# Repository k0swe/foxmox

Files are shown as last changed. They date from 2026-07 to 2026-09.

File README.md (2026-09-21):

# FoxMox V2.6

A KiCad reproduction of Larry Benko **W0QE**'s _Low Power FoxMOX Controller
V2.6_ (December 2004), transcribed by Chris Keller **K0SWE**.

FoxMox is a PIC16F84A-based amateur-radio foxhunt/ARDF beacon controller. It
keys and modulates an Alinco DJ-S11 through the radio's 2.5 mm microphone jack,
is powered by the jack's microphone-bias supply, and uses two hexadecimal rotary
switches for field configuration.

This repository includes the reconstructed hardware, the original scanned
schematic, recovered and hardware-tested firmware, readable assembly source, and
field operating instructions.

## Repository contents

| Path | Purpose |
| --- | --- |
| [`USER-GUIDE.md`](USER-GUIDE.md) | Field switch settings, timing profiles, and staggered five-fox startup. |
| [`Hardware/README.md`](Hardware/README.md) | Circuit behavior, radio interface, power constraints, R5 service strap, and bench checks. |
| [`Hardware/W0QE FoxMox scanned.pdf`](<Hardware/W0QE FoxMox scanned.pdf>) | Scan of the original W0QE schematic and source of truth for the hardware transcription. |
| `Hardware/foxmox.kicad_sch` / `Hardware/foxmox.kicad_pcb` | Reconstructed KiCad schematic and PCB. |
| [`Hardware/foxmox.pdf`](Hardware/foxmox.pdf) | Exported reconstructed schematic. |
| [`Firmware/README.md`](Firmware/README.md) | PIC programming, clock calibration, assembly builds, regression verification, and callsign generation. |
| `Firmware/foxmox-v2.6.hex` | Original recovered, hardware-tested PIC programming image. |
| `Firmware/foxmox-v2.6.asm` | Validated, readable gpasm source that reproduces the recovered image exactly. |

## Quick start

- For field setup, begin with [`USER-GUIDE.md`](USER-GUIDE.md).
- For hardware construction or troubleshooting, see
  [`Hardware/README.md`](Hardware/README.md).
- For PIC programming or firmware builds, see
  [`Firmware/README.md`](Firmware/README.md).

The default assembly build identifies as **N0PUF** and is regression-tested
byte-for-byte against the recovered programming image.

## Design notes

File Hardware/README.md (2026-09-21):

# FoxMox hardware

This directory contains the complete hardware design and its source references
for Larry Benko **W0QE**'s _Low Power FoxMOX Controller V2.6_ (December 2004),
transcribed by Chris Keller **K0SWE**.

| Path | Purpose |
| --- | --- |
| `foxmox.kicad_pro` | KiCad project entry point. |
| `foxmox.kicad_sch` | Reconstructed schematic. |
| `foxmox.kicad_pcb` | PCB layout. |
| `foxmox.pdf` | PDF export of the reconstructed schematic. |
| `W0QE FoxMox scanned.pdf` | Scan of Larry Benko W0QE's original schematic; source of truth for transcription. |
| `fp-lib-table`, `sym-lib-table` | Project-local KiCad library tables. |
| `Libraries/` | Project-local symbols, footprints, and 3D models. |
| `Datasheets/` | Component datasheets. |

Open `foxmox.kicad_pro` from this directory. Library references use
`${KIPRJMOD}/Libraries/...`, so moving the project and `Libraries/` together
preserves their relative paths.

The target radio in this build is the **Alinco DJ-S11**, connected through its
2.5 mm microphone jack.

## How the controller keys the radio

The DJ-S11 microphone jack has ground, a bias rail, and audio, but no separate
PTT contact. The microphone tip serves as both the audio input and PTT sense.
The radio biases that contact to power an electret microphone and watches its DC
level: pulling it toward ground through a resistor keys the transmitter;
releasing it returns the radio to receive. Transmit audio is AC-coupled onto the
same contact.

This resistive keying arrangement is common on Alinco, Icom, and Yaesu handheld
microphone interfaces. It does not depend on a VOX setting in the radio; VOX
accessories for these radios implement their own resistive pull-down. Kenwood
accessory wiring is a notable exception because it commonly provides a separate
PTT contact.

### Audio path — PIC RA0, pin 17

```text
RA0 ── R1 20k ── R2 5k pot ──(wiper)── C4 1 µF ── P1 tip
                      └── bottom ── GND
```

RA0 generates the square-wave tone. R1 and R2 attenuate it, while C4 blocks DC
so the tone does not disturb the keying level.

W0QE annotated the original drawing:

> Adjust for 20 to 40 mV peak to peak. Or set R2 for ~300 ohms from wiper to
> ground.

That setting is internally consistent: `3.0 V × 300 / 25000 ≈ 36 mV`. Avoid
excessive drive; the source waveform is already square and harmonic-rich.

### PTT path — PIC RA1, pin 18

```text
RA1 ── R3 20k ── Q1 base (2N2222A, emitter → GND)
                 Q1 collector ── R4 2.7k ── P1 tip
```

RA1 high saturates Q1 and pulls the microphone tip toward ground through R4.
**R4, 2.7 kΩ, is the radio's keying resistor.** RA1 low turns Q1 off and allows
the microphone contact to return to its bias voltage.

Both paths meet at the microphone tip. In the PCB netlist, `Net-(C4-Pad2)`
contains `C4.2`, `P1.T`, and `R4.2`.

## Power source and current budget

The controller has no battery of its own. It is parasitically powered by the
radio's microphone-bias rail:

```text
P1 ring ── S3 (SPDT power switch) ── VDD ── U1.14, U1.4 (MCLR), C3, D1, TP1
P1 sleeve ── GND
```

W0QE recorded:

> Measured current draw @ 3.0 V from Ring to Sleeve = **0.5 mA idle, 0.9 mA
> transmitting**

This sub-milliamp supply is a binding design constraint. It explains the
PIC16F84, resistively attenuated square-wave audio, and absence of more
power-hungry circuitry. Before substituting another MCU, verify that its
complete idle and transmit current does not collapse the microphone-bias rail or
false-key the radio.

D1 is a 6.2 V zener used for overvoltage protection. It is not regulating the
normal approximately 3 V supply.

## R5 is the boot/service-mode strap

R5, 10 kΩ, is intentionally connected between **RA2 (PIC pin 1)** and **RA3 (PIC
pin 2)**. **RA4/T0CKI (PIC pin 3) is unconnected. Do not move R5 to RA4.**

The original scan is easy to misread:

1. The `R5 10k` text is printed below its resistor body, placing the label near
   the RA4 row even though the component itself connects RA2 to RA3. Component
   label placement in this drawing is not a reliable indication of connectivity.
2. The X on the RA4 row is a printed no-connect mark. The pin stub ends at that
   mark; it is not a wire crossed out by hand. Pixel measurements support that
   reading: its darkness matches printed material rather than the lighter pencil
   handwriting elsewhere on the scan.

   | Scan feature                     | Mean gray |
   | -------------------------------- | --------: |
   | Printed wire                     |        73 |
   | RA4 X mark                       |        81 |
   | Printed text                     |        89 |
   | Pencil handwriting at top margin |       140 |

The reconstructed schematic has an explicit RA4 no-connect at `(97.79, 105.41)`;
with U1 placed at `(80.01, 110.49)`, that location resolves to PIC pin 3. The
PCB independently names the pad `unconnected-(U1-TOCKI{slash}RA4-Pad3)`. The
reconstructed schematic and PCB therefore agree.

The firmware also proves R5's purpose: at reset RA3 is driven high while RA2 is
an input, so R5 pulls RA2 high for normal startup. Holding RA2 low during
startup enters the clock-calibration service mode; the firmware waits for RA2 to
be released before continuing. Moving R5 to RA4 would break that boot test.

The service-mode procedure is documented in
[`../Firmware/README.md`](../Firmware/README.md).

## Bench checks with an Alinco DJ-S11

Before relying on a rebuilt controller in the field, check it with the actual
radio and cable:

1. **Bias supply:** measure approximately 3 V from ring to sleeve and confirm it
   can source at least 1 mA without excessive sag.
2. **PTT keying:** confirm that the 2.7 kΩ pull-down keys reliably with both a
   fresh radio battery and a nearly discharged one. The microphone-bias voltage
   can move with battery condition.
3. **Audio level:** begin with R2 adjusted to approximately 300 Ω from wiper to
   ground, then verify 20–40 mV peak-to-peak or check deviation on a service
   monitor or trusted receiver.

## Verifying the transcription

The scanned schematic is lossy and its geometry is easy to misread. Use these
sources in descending order of confidence:

1. Treat `W0QE FoxMox scanned.pdf` as the source of truth for the original
   design.
2. Use the resolved nets in `foxmox.kicad_pcb` when checking the reconstructed
   connectivity. Footprint pad records carry their net names and avoid visual
   wire-tracing mistakes.
3. Cross-check hardware-dependent behavior against
   [`../Firmware/foxmox-v2.6.asm`](../Firmware/foxmox-v2.6.asm).
4. For close inspection of the scan, render it at high resolution:

   ```sh
   pdftoppm -r 300 -png "Hardware/W0QE FoxMox scanned.pdf" out
   ```

`Hardware/.history/` and `*.kicad_prl` are intentionally ignored by the outer
repository. They are local KiCad state, not versioned design artifacts.

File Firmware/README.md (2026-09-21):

# FoxMox firmware

This directory contains the recovered and hardware-tested firmware for the W0QE
FoxMOX V2.6 controller built around a PIC16F84A.

## Contents

| Path | Purpose |
| --- | --- |
| `foxmox-v2.6.asm` | Validated, readable gpasm source for the complete firmware. |
| `foxmox-v2.6.hex` | Original recovered programming image and exact-build regression oracle. |
| `Makefile` | Default exact build plus custom-callsign image builds. |
| `emit_callsign.py` | Validates a callsign and emits its Morse calls plus layout padding. |
| `verify_image.py` | Compares all programmed regions against the recovered image. |
| `canonicalize_hex.py` | Normalizes gpasm output to the recovered Intel HEX representation. |
| `test_emit_callsign.py` | Unit tests for callsign generation and fixed-layout compensation. |
| `requirements.txt` | Pinned Python package needed to operate a K150 with `picpro`. |

`foxmox-v2.6.hex` was reconstructed from two original FoxMox PIC16F84A chips.
Each chip was read twice. All four ROM reads and all four configuration reads
matched. The two reads from each chip's EEPROM matched; the committed image uses
the first chip's EEPROM. A newly programmed blank PIC reproduced the correct
behavior in an original FoxMox circuit.

SHA-256:

```text
fd2546d702d7f152492bd81f077fed141b5110a9ec950f8becbee85d6fce2018  foxmox-v2.6.hex
```

The disposable raw binary reads were removed after reconstruction and
verification. Their SHA-256 provenance is retained here:

| Original reads | SHA-256 |
| --- | --- |
| ROM reads 1–4 | `546781166e6c349ccbb167d5767dacbf99e84a844c02573d8a7d724120fe6fbd` |
| Config reads 1–4 | `ef243db2cd17e4bd231702d4772631d3d2b1c6517537b5ffe5ee716e1d2c0511` |
| EEPROM reads 1–2 (chip 1; used here) | `1717c8d193e79f42a47fa1c73697095e1c3cf7151fb5c31dcc71067034cc6e31` |
| EEPROM reads 3–4 (chip 2) | `ec9046ee89c522c35967271c6c3d923df622bfac4652ae824c0369186abe2a14` |

The two EEPROM images differed only at logical addresses `0x00` and `0x28`.

## K150 placement for the PIC16F84A

On the common 40-pin K150 ZIF socket:

- orient PIC pin 1 toward the **lever end**;
- align PIC pin 1 with **ZIF position 2**, leaving ZIF position 1 empty;
- the 18-pin device therefore occupies ZIF positions 2–10 and 31–39.

An incorrect position returns plausible-looking default data identical to an
empty socket, including a zero device ID. Correct placement returns the expected
PIC16F84A silicon ID `0x0560`.

Disconnect USB before inserting, removing, or repositioning a PIC.

## Re-create the picpro environment

From the repository root:

```sh
python3 -m venv .venv
.venv/bin/python -m pip install --upgrade pip
.venv/bin/python -m pip install -r Firmware/requirements.txt
```

The tested version is `picpro 0.4.1`. The K150 used here reports firmware
version 3 and the required P18A protocol:

```sh
.venv/bin/picpro programmer_info -p /dev/ttyUSB0
```

Expected:

```text
Firmware version: 3
Protocol version: P18A
```

If access to `/dev/ttyUSB0` is denied, add the user to the distribution's serial
port group (commonly `dialout`) and start a new login session.

## Safely identify and read a chip

Read-only configuration check:

```sh
.venv/bin/picpro read_chip_config -p /dev/ttyUSB0 -t 16f84a
```

A connected PIC16F84A should return `Chip ID: 1376 (0x560)`. The recovered
FoxMox configuration word is `0x3FF1`, decoded as:

```text
WDT = Disabled
PWRTE = Enabled
Oscillator = XT
Code Protect = Disabled
```

Read all three regions as binary files into a scratch directory:

```sh
mkdir -p /tmp/foxmox-read
.venv/bin/picpro dump rom \
  -p /dev/ttyUSB0 -t 16f84a --binary \
  -o /tmp/foxmox-read/rom.bin
.venv/bin/picpro dump eeprom \
  -p /dev/ttyUSB0 -t 16f84a --binary \
  -o /tmp/foxmox-read/eeprom.bin
.venv/bin/picpro dump config \
  -p /dev/ttyUSB0 -t 16f84a --binary \
  -o /tmp/foxmox-read/config.bin
```

Read twice and compare hashes before treating a recovery as trustworthy. The
committed combined HEX remains the canonical recovered image; the disposable
raw-read reconstruction utility was retired after the readable assembly was
proved byte-identical across every programmed region.

## Program and verify a replacement PIC

**Programming erases and overwrites the chip currently in the socket. Never run
this against one of the originals.** Confirm that a replaceable blank PIC is
installed first.

```sh
.venv/bin/picpro program \
  -p /dev/ttyUSB0 -t 16f84a \
  -i Firmware/foxmox-v2.6.hex

.venv/bin/picpro verify \
  -p /dev/ttyUSB0 -t 16f84a \
  -i Firmware/foxmox-v2.6.hex
```

The strongest practical check is to install the replacement in an original
FoxMox controller and confirm its on-air behavior; that validation has already
succeeded for this committed image.

## Calibrate the one-second time base

The firmware stores an unsigned clock-trim byte in data EEPROM address `0x28`.
The recovered chip-1 image contains `0xFF`; this is a runtime setting, not the
PIC programmer's unrelated generic `CAL` field.

Every 64th nominal second, the timer ISR adds the trim byte to that one
software-divider interval. Consequently:

- increasing the value makes firmware seconds and all timed phases **longer**;
- decreasing the value makes them **shorter**;
- one count changes the average rate by approximately **4.472 ppm**.

There is no universal target byte: crystal frequency, loading, supply voltage,
and temperature all affect the correct setting. Measure the assembled controller
rather than copying another unit's value.

The firmware's service interface was reconstructed from code. No surviving
factory instruction identifies the original fixture or contact used to ground
RA2. On an unmodified board, use a temporary, controlled connection to RA2 only
if you are comfortable working directly at the PIC; RA2 is PIC pin 1. During the
boot test RA2 is an input pulled high from RA3 through R5 (10 kOhm). **Do not
leave RA2 grounded:** after service entry the firmware changes RA2 to an output.

### Measure the error

Use a stable reference clock and measure complete PTT cycles rather than Morse
element lengths. A convenient setup is S1=`0` through `4` and S2=`6`, whose
normal cycle is 60 seconds transmitting plus 240 seconds silent, or 300 firmware
seconds. Ignore the one-time transmission immediately after power-on and time
from one later PTT assertion to the same edge after several complete cycles.
Twelve cycles give a nominal one-hour observation.

For a one-hour measurement:

```text
trim change ≈ (3600.000 s - measured seconds) / 0.016091 s
```

Round to the nearest whole count:

- a measurement shorter than 3600 seconds means the firmware is fast, so
  **increase** the trim;
- a measurement longer than 3600 seconds means it is slow, so **decrease** the
  trim.

For an arbitrary observation of `N` nominal firmware seconds, the equivalent
calculation is:

```text
trim change ≈ (N - measured seconds) / (N × 4.47195e-6)
```

This is a first-order correction. Re-measure after adjustment, preferably over a
longer interval and at the expected field temperature.

### Enter service mode and change the value

Service mode keys the transmitter and announces values over the radio. Use a
dummy load or an authorized test frequency and identify as required.

1. Power the controller off.
2. Set **S1=`1` and S2=`2`**. This keeps the combined switch value nonzero while
   selecting a no-change S2 position.
3. Hold RA2 low and apply power.
4. Release RA2. The firmware waits for a stable high level, enters service mode,
   keys the transmitter, and sends the current trim as two hexadecimal Morse
   characters.
5. Use S2 to adjust or hold the value:

   |        S2 position | Service-mode action                                   |
   | -----------------: | :---------------------------------------------------- |
   | `1`, `3`, `5`, `7` | Increment the trim                                    |
   |            `8`–`F` | Decrement the trim                                    |
   |      `2`, `4`, `6` | Hold without changing it                              |
   |                `0` | Exit service mode after the five-second service timer |

   S2 positions that change the value repeat the operation while selected. Each
   new value is written immediately to EEPROM `0x28` and announced in
   hexadecimal Morse. Return S2 to `2` after the desired number of steps.

6. Turn S2 to `0` and wait. The firmware announces the stored value again,
   restarts, and enters normal operation using the new trim.
7. Power off, remove any temporary RA2 connection, restore the desired S1/S2
   operating settings, and repeat the timing measurement.

Do not enter service mode with both switches at zero. That combination branches
to the firmware's halt/blink loop instead of the adjustment interface. The trim
arithmetic wraps at `00`/`FF`; there is no saturation check, so count carefully
near either endpoint.

## Build and verify the assembly source

`foxmox-v2.6.asm` is the maintained firmware source. Every executable program
word is readable gpasm; the remaining `DW 0x3FFF` values intentionally represent
erased reset padding and the variable gap before the fixed page-3 tables.

Install the open-source, MPASM-compatible `gputils` assembler:

```sh
sudo apt install gputils
```

The validated toolchain is `gpasm-1.4.0 #1107 (Jan 1 2021)`. Build the default
`N0PUF` image and compare its program ROM, configuration word, EEPROM, user-ID
nibbles, emitted regions, and canonical Intel HEX against the recovered image:

```sh
make -C Firmware verify
```

The final canonical image is `Firmware/build/foxmox-v2.6.hex`. A successful
build reports both lossless programmed-memory equivalence and byte-for-byte
canonical HEX identity.

### Build a different callsign

The identification callsign is compiled into program memory and defaults to the
recovered value, `N0PUF`. Build a custom alphanumeric callsign with:

```sh
make -C Firmware image CALLSIGN=K0SWE BUILD_DIR=build/K0SWE
```

This creates `Firmware/build/K0SWE/foxmox-v2.6.hex`. Supported characters are
`A-Z` and `0-9`; lowercase is normalized and punctuation is rejected. The
emitter adjusts erased padding so callsigns of different lengths cannot move
`hex_digit_dispatch` from `0x300` or `tone_pattern_lookup` from `0x367`; an
assembler assertion fails closed if the boundary changes.

`make verify` is intentionally limited to `N0PUF`, because a customized image
must differ from the recovered regression oracle. Run the callsign tests alone
with:

```sh
make -C Firmware test
```

Remove generated output with:

```sh
make -C Firmware clean
```

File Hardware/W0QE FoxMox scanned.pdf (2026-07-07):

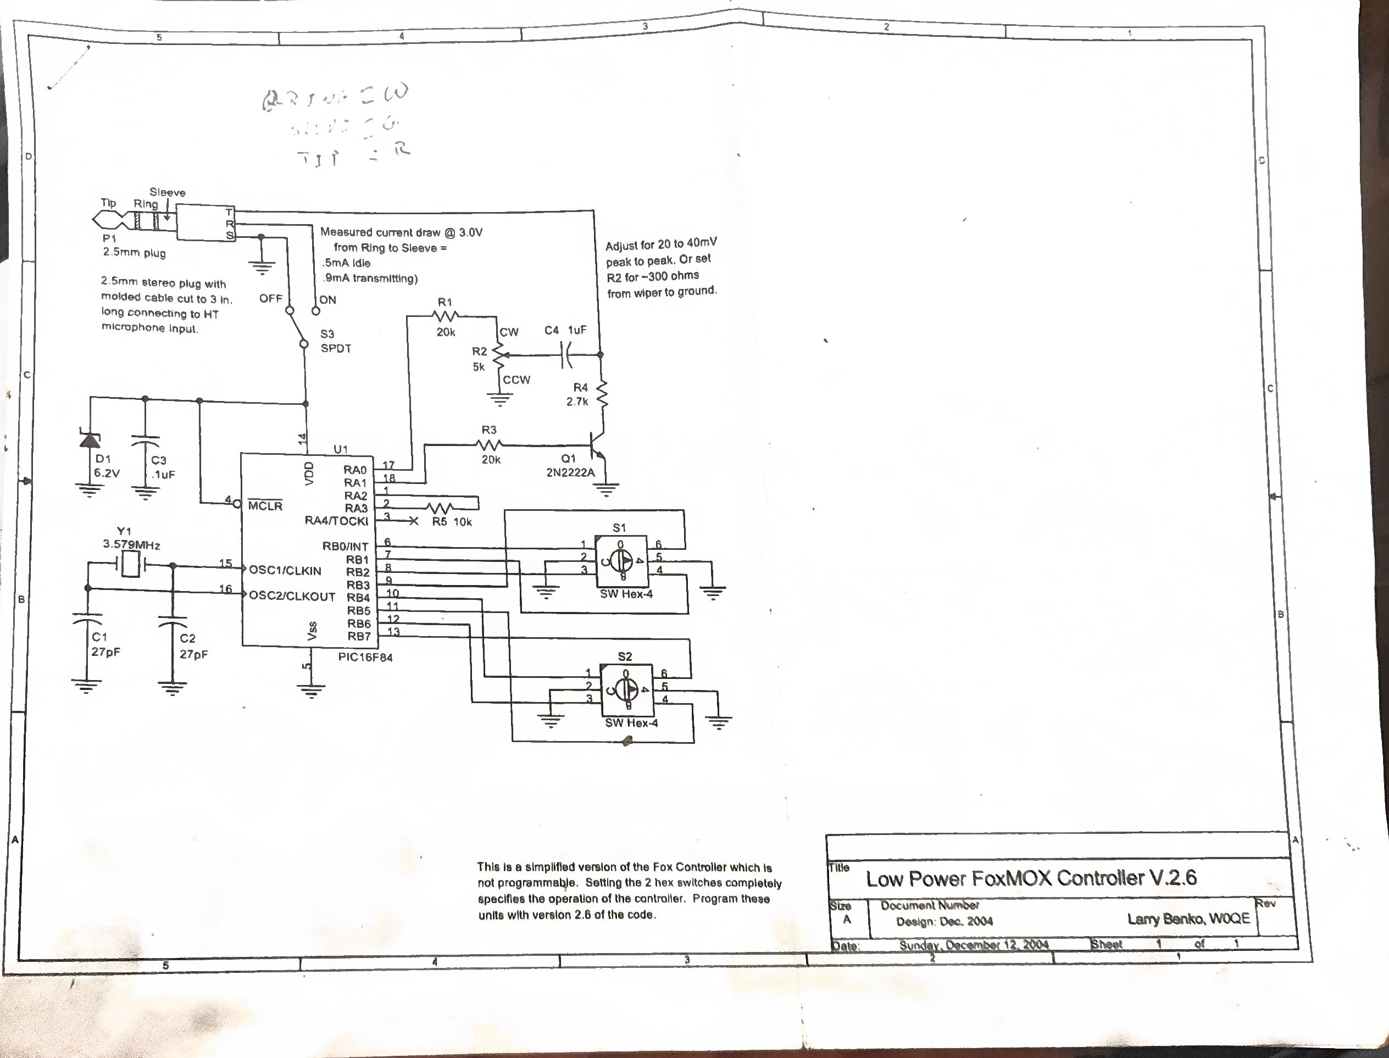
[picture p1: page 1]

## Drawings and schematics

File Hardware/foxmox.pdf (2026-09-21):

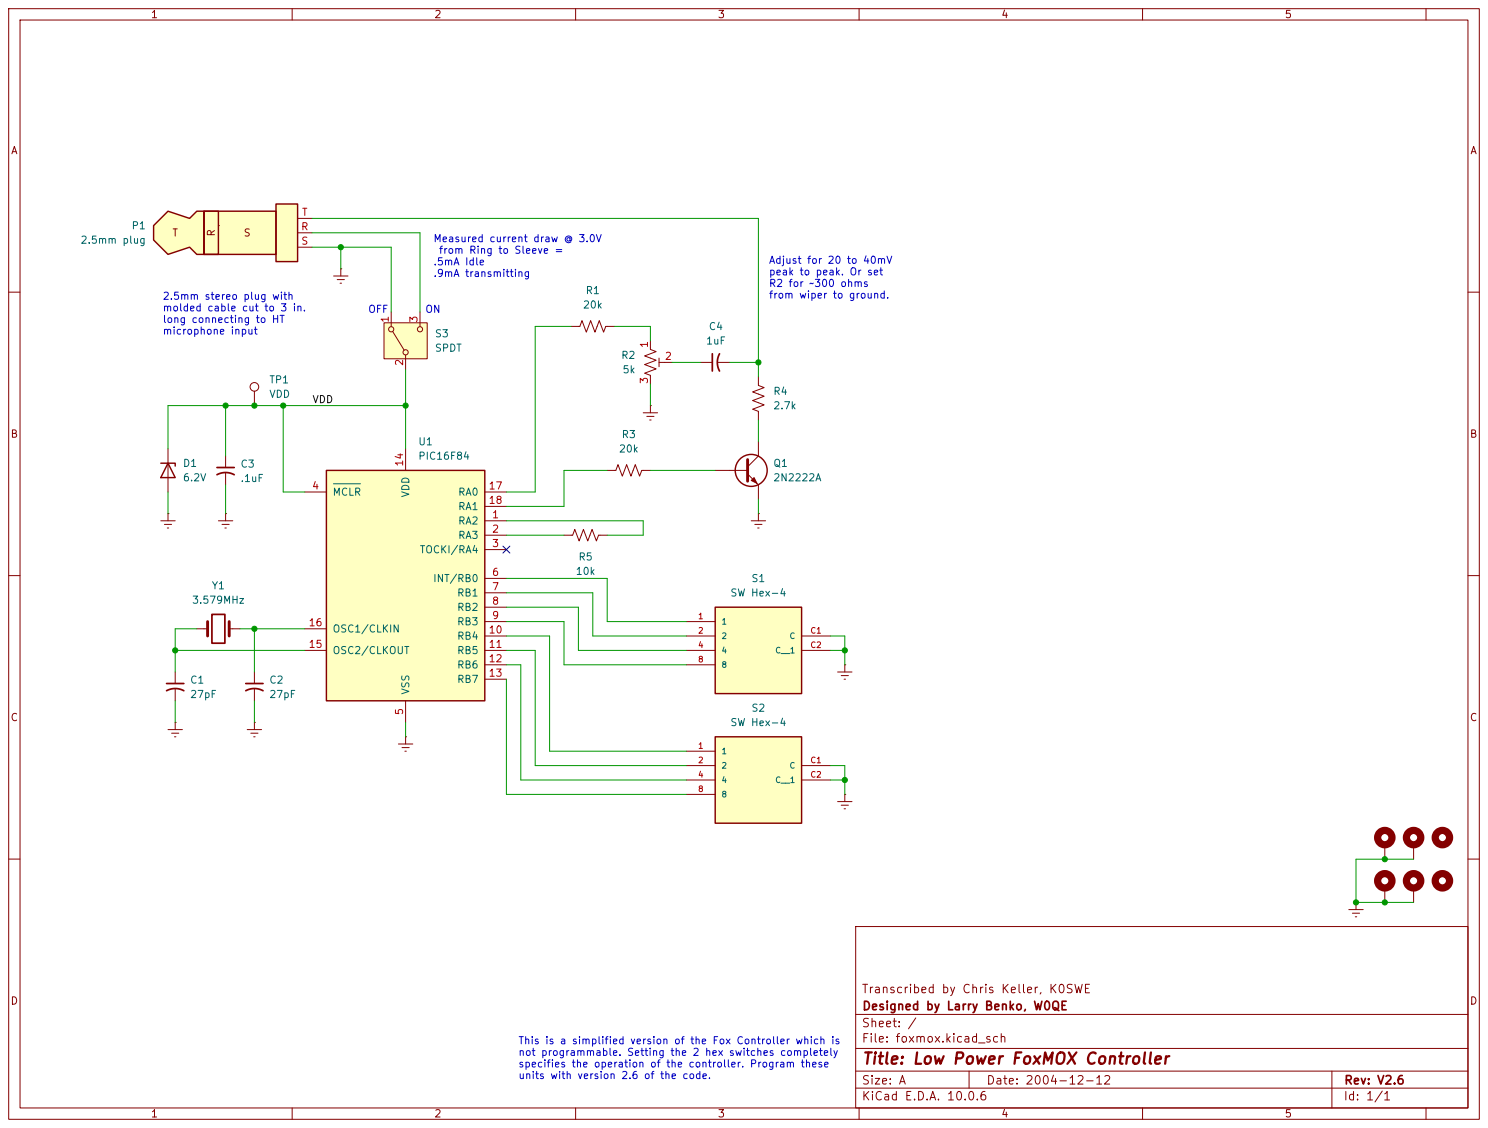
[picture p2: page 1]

Adjust for 20 to 40mV peak to peak. Or set R2 for ~300 ohms

from wiper to ground.

Transcribed by Chris Keller, K0SWE
Designed by Larry Benko, W0QE
Sheet: /
File: foxmox.kicad_sch
Title: Low Power FoxMOX Controller

This is a simplified version of the Fox Controller which is not programmable. Setting the 2 hex switches completely

specifies the operation of the controller. Program these units with version 2.6 of the code.

Size: A | Rev: V2.6
KiCad E.D.A. 10.0.6 | Id: 1/1

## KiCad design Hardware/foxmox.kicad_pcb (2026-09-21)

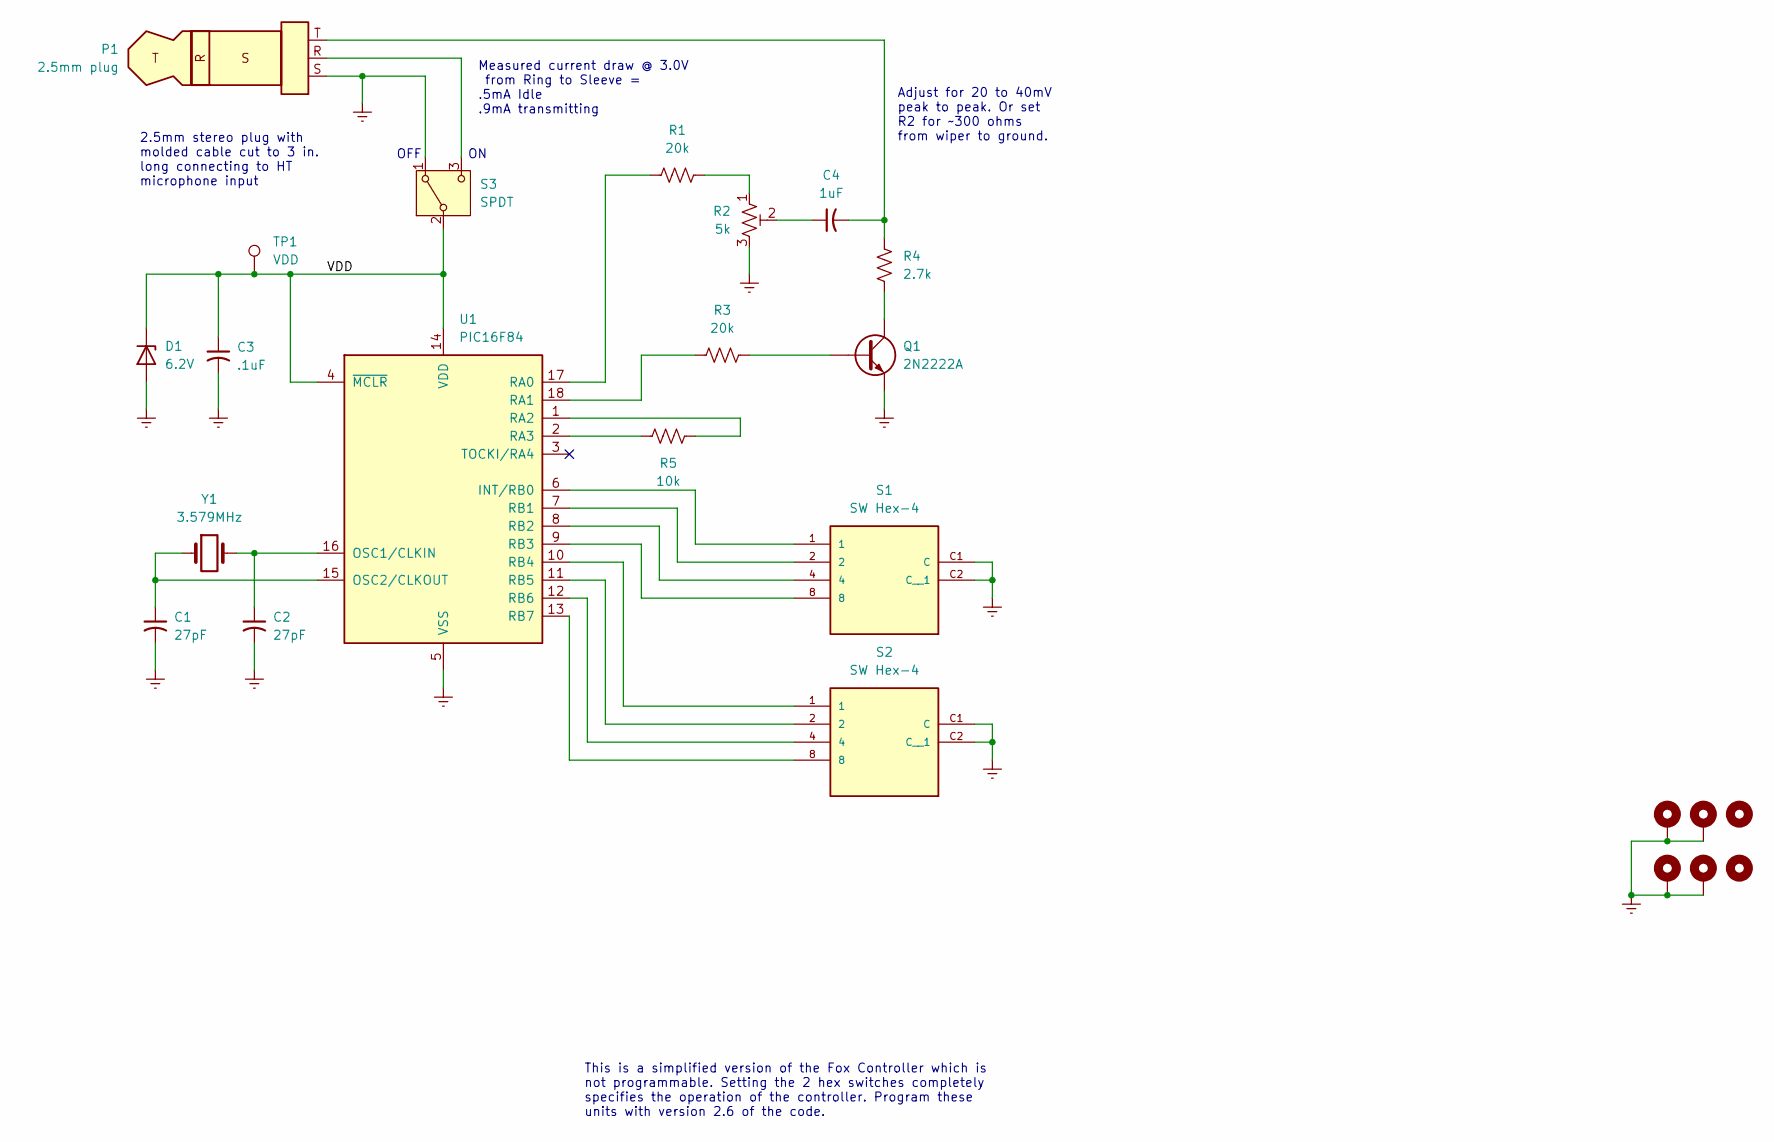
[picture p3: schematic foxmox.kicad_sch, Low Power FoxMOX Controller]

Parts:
C1, C2: 27pF; C_Disc_D4.3mm_W1.9mm_P5.00mm
C3: .1uF; C_Disc_D7.5mm_W5.0mm_P7.50mm
C4: 1uF; C_Disc_D7.5mm_W5.0mm_P7.50mm
D1: 6.2V; D_DO-35_SOD27_P7.62mm_Horizontal
H1, H2, H3, H4: MountingHole; MountingHole_2.5mm_Pad
H5, H6: MountingHole; MountingHole_2mm
P1: 2.5mm plug; TerminalBlock_Xinya_XY308-2.54-3P_1x03_P2.54mm_Horizontal
Q1: 2N2222A; TO-92_Inline_Wide
R1, R3: 20k; R_Axial_DIN0207_L6.3mm_D2.5mm_P15.24mm_Horizontal
R2: 5k; Potentiometer_Bourns_3266W_Vertical
R4: 2.7k; R_Axial_DIN0207_L6.3mm_D2.5mm_P15.24mm_Horizontal
R5: 10k; R_Axial_DIN0207_L6.3mm_D2.5mm_P15.24mm_Horizontal
S1, S2: SW Hex-4; SW_RDS5-16S-1065-D-67; PARTREV 1.0
S3: SPDT; SW_1218_EWI
TP1: VDD; TestPoint_Pad_D2.0mm
U1: PIC16F84; CERDIP-18_W7.62mm_SideBrazed
Y1: 3.579MHz; Crystal_HC49-4H_Vertical

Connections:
/VDD: C3.1, D1.1 (K), S3.2 (B), TP1.1 (1_1), U1.4 (~MCLR), U1.14 (VDD)
GNDREF: C1.2, C2.2, C3.2, D1.2 (A), H1.1 (1_1), H2.1 (1_1), H3.1 (1_1), H4.1 (1_1), P1.S, Q1.1 (E), R2.3, S1.C1 (C), S1.C2 (C__1), S2.C1 (C), S2.C2 (C__1), S3.1 (A), U1.5 (VSS)
unnamed: C4.1, R2.2
unnamed: C4.2, P1.T, R4.2
unnamed: Q1.2 (B), R3.2
unnamed: Q1.3 (C), R4.1
unnamed: R1.2, R2.1
unnamed: P1.R, S3.3 (C)
unnamed: S1.1, U1.6 (INT/RB0)
unnamed: C2.1, U1.16 (OSC1/CLKIN), Y1.2
unnamed: C1.1, U1.15 (OSC2/CLKOUT), Y1.1
unnamed: R1.1, U1.17 (RA0)
unnamed: R3.1, U1.18 (RA1)
unnamed: R5.2, U1.1 (RA2)
unnamed: R5.1, U1.2 (RA3)
unnamed: S1.2, U1.7 (RB1)
unnamed: S1.4, U1.8 (RB2)
unnamed: S1.8, U1.9 (RB3)
unnamed: S2.1, U1.10 (RB4)
unnamed: S2.2, U1.11 (RB5)
unnamed: S2.4, U1.12 (RB6)
unnamed: S2.8, U1.13 (RB7)

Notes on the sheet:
OFF
Adjust for 20 to 40mV peak to peak. Or set R2 for ~300 ohms from wiper to ground.
This is a simplified version of the Fox Controller which is not programmable. Setting the 2 hex switches completely specifies the operation of the controller. Program these units with version 2.6 of the code.
Measured current draw @ 3.0V from Ring to Sleeve = .5mA Idle .9mA transmitting
2.5mm stereo plug with molded cable cut to 3 in. long connecting to HT microphone input

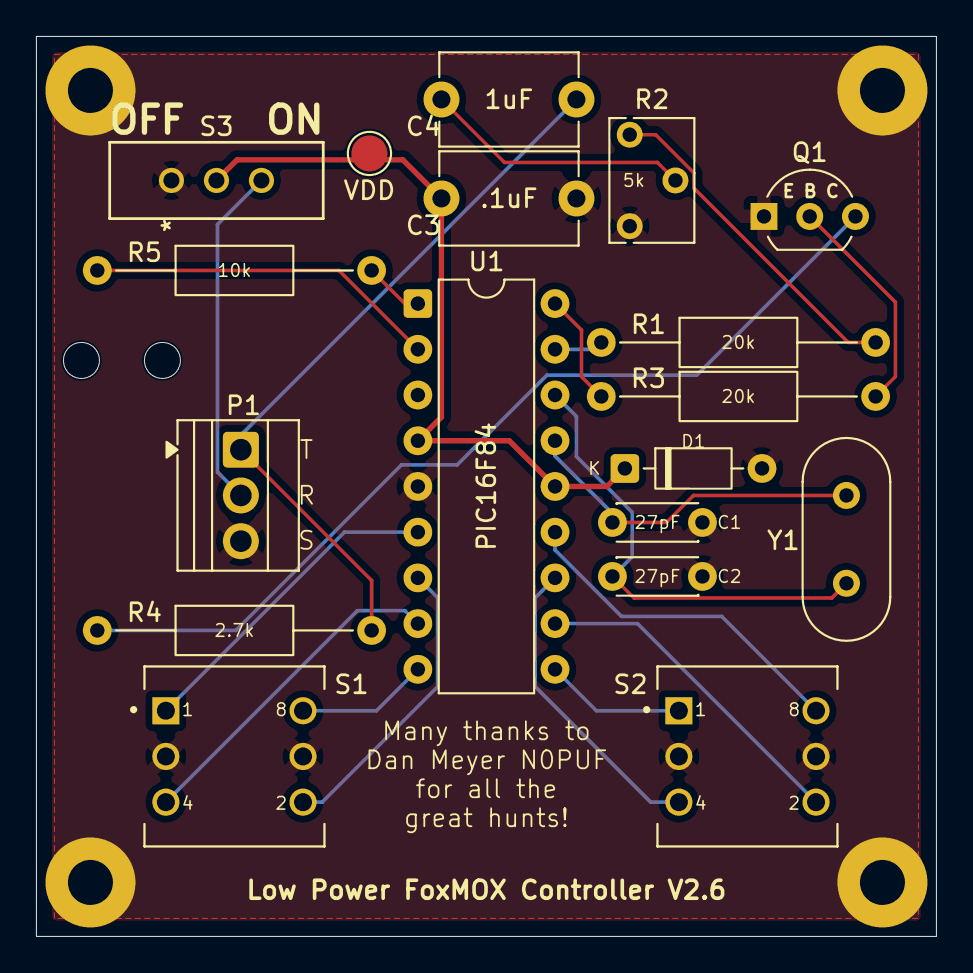
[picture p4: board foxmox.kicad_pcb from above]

Board: 2 copper layers, 50.0 x 50.0 mm, 24 parts (0 on the bottom side), 22 nets.

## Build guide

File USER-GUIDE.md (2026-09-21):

# FoxMox V2.6 User Guide

This guide covers ordinary field setup of a FoxMox controller running the
reconstructed V2.6 firmware. For programmer wiring, chip recovery, and exact
build verification, see [`Firmware/README.md`](Firmware/README.md).

## Callsign: programmed into the PIC

The station callsign is fixed in the PIC16F84A firmware. It is **not field
programmable**, and neither rotary switch changes it. The callsign is separate
from the fox message selected by S1. Confirm that each controller contains a PIC
programmed with the intended callsign before deployment.

The recovered firmware identifies as **N0PUF**. Changing it requires rebuilding
the firmware and reprogramming the PIC; see
[`Firmware/README.md`](Firmware/README.md).

## Set the switches before applying power

The two hexadecimal rotary switches select operating behavior:

- **S1** selects the transmitted fox or practice message.
- **S2** selects the transmit/silent timing profile and, for some settings, a
  one-time startup delay.

The firmware samples them at startup and again at points in the operating cycle.
Set both switches while the controller is off; changing them live can combine an
old phase with a newly sampled setting. The unit transmits its selected S1
message once shortly after power is applied, then observes the selected startup
delay and enters its repeating transmit/silent cycle.

### S1: transmitted message

|  S1 | Transmitted message | Typical use |
| --: | :--- | :--- |
| `0` | `MOE` | Fox 1 |
| `1` | `MOI` | Fox 2 |
| `2` | `MOS` | Fox 3 |
| `3` | `MOH` | Fox 4 |
| `4` | `MO5` | Fox 5 |
| `5` | `MO` | Alternate/practice message |
| `6` | `A` | Alternate/practice message |
| `7` | `B` | Alternate/practice message |
| `8` | `F` | Alternate/practice message |
| `9` | `L` | Alternate/practice message |
| `A` | `N` | Alternate/practice message |
| `B` | `P` | Alternate/practice message |
| `C` | `V` | Alternate/practice message |
| `D` | `X` | Alternate/practice message |
| `E` | `Z` | Alternate/practice message |
| `F` | `FOX` | General fox/practice message |

## S2 timing for the five standard fox identities

Use this table when S1 is `0` through `4`. Durations are nominal whole seconds;
the clock-calibration value stored in EEPROM can shift them slightly.

|  S2 | Transmit | Silent | Cycle | Startup delay |
| --: | ---: | -----: | ----: | ---: |
| `0` | 20 s | 40 s | 1 min | none |
| `1` | 20 s |  100 s | 2 min | none |
| `2` | 24 s | 96 s | 2 min | none |
| `3` | 36 s |  144 s | 3 min | none |
| `4` | 40 s | 80 s | 2 min | none |
| `5` | 48 s |  192 s | 4 min | none |
| `6` | 60 s |  240 s | 5 min | none |
| `7` | 60 s |  240 s | 5 min | 30 min |
| `8` | 20 s | 40 s | 1 min | 30 min |
| `9` | 20 s |  100 s | 2 min | 60 min |
| `A` | 24 s | 96 s | 2 min | 60 min |
| `B` | 36 s |  144 s | 3 min | 60 min |
| `C` | 40 s | 80 s | 2 min | 60 min |
| `D` | 48 s |  192 s | 4 min | 60 min |
| `E` | 60 s |  240 s | 5 min | 60 min |
| `F` | 60 s |  240 s | 5 min | 120 min |

Cadence and startup delay are selected independently. Cadence uses only the low
three S2 bits, so `0`/`8`, `1`/`9`, …, and `7`/`F` are cadence pairs. For the
standard fox identities, however, the startup-delay groups are `0`–`6` = none,
`7`–`8` = 30 minutes, `9`–`E` = 60 minutes, and `F` = 120 minutes. Therefore
**S2=`7` really does have a 30-minute startup delay**; use S2=`6` for the same
60-second transmit / 240-second silent cadence with no startup delay.

## S2 timing for alternate messages

Use this table when S1 is `5` through `F`.

|  S2 | Transmit | Silent | Cycle | Startup delay | Additional behavior |
| --: | ---: | -----: | ----: | ---: | :--- |
| `0` | 12 s | 24 s |  36 s | none | — |
| `1` | 20 s | 20 s |  40 s | none | — |
| `2` | 20 s | 40 s | 1 min | none | — |
| `3` | 20 s |  100 s | 2 min | none | — |
| `4` | 12 s | 36 s |  48 s | none | — |
| `5` | 16 s | 48 s |  64 s | none | — |
| `6` | 16 s | 64 s |  80 s | none | — |
| `7` | 60 s | 0 s | 1 min | none | — |
| `8` | 12 s | 24 s |  36 s | 60 min | — |
| `9` | 20 s | 20 s |  40 s | 60 min | — |
| `A` | 20 s | 40 s | 1 min | 60 min | — |
| `B` | 20 s |  100 s | 2 min | 60 min | — |
| `C` | 12 s | 36 s |  48 s | 60 min | Adds 0–31 s pseudo-random silent jitter |
| `D` | 16 s | 48 s |  64 s | 60 min | Adds 0–31 s pseudo-random silent jitter |
| `E` | 16 s | 64 s |  80 s | 60 min | Adds 0–31 s pseudo-random silent jitter |
| `F` | 60 s | 0 s | 1 min | 60 min | — |

The jitter is added to the silent phase. It applies only to S1=`5` through `F`
with S2=`C`, `D`, or `E`.

## Standard five-fox round robin

For the familiar five-fox sequence—one fox transmitting for one minute, then
silent for four minutes—configure five independent controllers as follows:

| Unit |  S1 | Message |  S2 |
| ---: | --: | :--- | --: |
| 1 | `0` | `MOE` | `6` |
| 2 | `1` | `MOI` | `6` |
| 3 | `2` | `MOS` | `6` |
| 4 | `3` | `MOH` | `6` |
| 5 | `4` | `MO5` | `6` |

S2=`6` gives each unit a 60-second transmit phase followed by 240 seconds of
silence, with no built-in startup delay.

### Staggered power-on procedure

The controllers do not communicate with one another, listen for another fox, or
synchronize over the air. **The time at which each unit is powered establishes
its phase.**

1. Set S1/S2 on all five powered-off units as shown above.
2. At `T+0:00`, power Fox 1 (`MOE`).
3. At `T+1:00`, power Fox 2 (`MOI`).
4. At `T+2:00`, power Fox 3 (`MOS`).
5. At `T+3:00`, power Fox 4 (`MOH`).
6. At `T+4:00`, power Fox 5 (`MO5`).
7. Monitor one complete five-minute cycle and confirm the order before
   deployment.

Each controller sends its selected message shortly after power-on, before its
normal timed phase begins. Those one-time startup announcements can briefly
overlap the preceding fox during setup; judge the round robin from the first
complete cycle after all five units are running. Perform the sequence on the
intended operating frequency only when those setup transmissions are acceptable.
Powering all five at the same time would put their normal cycles at
approximately the same phase and cause continuing overlap.

The clocks are crystal-derived but independent. For long events, allow for some
drift and verify the sequence before participants start. If a unit loses power,
its phase is lost; restore the intended sequence by powering it again at the
correct point in the five-minute cycle.

## Other useful configurations

- **Single continuously repeating practice fox:** S1=`F`, S2=`7` gives `FOX`
  with a nominal 60-second transmit phase and no silent phase.
- **One-minute fox cycle:** S1=`0` through `4`, S2=`0` gives 20 seconds on and
  40 seconds silent, with no startup delay.
- **Delayed deployment:** upper-half S2 settings (`8`–`F`) retain a lower-half
  cadence but add a 30-, 60-, or 120-minute startup delay as shown in the
  tables. In the standard S1=`0`–`4` modes, S2=`7` also has a 30-minute delay.
  The unit still sends its selected message once immediately after power-on
  before waiting through that delay.

## Operational cautions

- Set S1 and S2 before power-on; do not rely on changing them during a cycle.
- The callsign and S1 message are separate: changing S1 never changes the
  programmed callsign.
- The controller is powered from the radio microphone-bias supply. Confirm the
  radio and cable can provide the required current before field deployment.
- Verify deviation and reliable PTT keying with the actual radio and battery
  condition being used.
- Program only a replaceable PIC. Keep recovered original chips read-only.

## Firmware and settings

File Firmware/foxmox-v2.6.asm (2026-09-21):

; FoxMox V2.6 — lossless PIC16F84A reconstruction
;
; This first preservation source intentionally emits recovered instruction
; words with DW. Labels and decoded comments are documentary; replacing a DW
; with a mnemonic is safe only when verification still reports exact equality.
; Canonical image: ../foxmox-v2.6.hex

        LIST      P=16F84A, F=INHX8M
        INCLUDE   <p16f84a.inc>
        RADIX     HEX

; RAM aliases established by the interrupt and main-loop data flow.
isr_w_save      EQU       0x0C
isr_status_save EQU       0x0D
second_div_hi   EQU       0x0E
second_div_lo   EQU       0x0F
seconds_mod64   EQU       0x10
tmr0_wait_count EQU       0x11
message_seconds EQU       0x12
phase_counter_hi EQU      0x13
phase_counter_lo EQU      0x14
callsign_cooldown_hi EQU  0x15
callsign_cooldown_lo EQU  0x16
morse_unit_ticks EQU      0x19
porta_shadow    EQU       0x1A
switch_state    EQU       0x1B
service_delay_lo EQU      0x1E
service_delay_hi EQU      0x1F
tone_phase      EQU       0x1C
tone_state      EQU       0x1D
lfsr_state      EQU       0x20
hex_digit_index EQU       0x22
lfsr_steps      EQU       0x23
saved_w         EQU       0x25
interrupt_flag  EQU       0x27
hex_byte        EQU       0x28
tone_pattern    EQU       0x29
message_index   EQU       0x2B
timing_record_addr EQU    0x2C
timing_trim     EQU       0x3F

; PIC14 instructions encode seven file-address bits; RP0 supplies the bank.
; These aliases keep bank-1 register names visible without gpasm's expected
; "register not in bank 0" advisory for their absolute header values.
OPTION_REG_FILE EQU       (OPTION_REG & 0x7F)
TRISA_FILE      EQU       (TRISA & 0x7F)
TRISB_FILE      EQU       (TRISB & 0x7F)
EECON1_FILE     EQU       (EECON1 & 0x7F)
EECON2_FILE     EQU       (EECON2 & 0x7F)

        ORG       0x0000

reset_vector:
        GOTO      startup
        DW        0x3FFF ; erased (instruction encoding: addlw 0xFF)
        DW        0x3FFF ; erased (instruction encoding: addlw 0xFF)
        DW        0x3FFF ; erased (instruction encoding: addlw 0xFF)

interrupt_vector:
        GOTO      tmr0_isr

tmr0_isr:
        MOVWF     isr_w_save
        MOVF      STATUS, W
        MOVWF     isr_status_save
        BCF       INTCON, T0IF
        BCF       STATUS, RP0 ; bank 0
        MOVF      porta_shadow, W
        MOVWF     PORTA

        DECFSZ    second_div_lo, F
        GOTO      isr_tone_update
        DECFSZ    second_div_hi, F
        GOTO      isr_tone_update
        MOVLW     0xA6
        MOVWF     second_div_lo
        MOVLW     0x0E
        MOVWF     second_div_hi

        MOVF      message_seconds, F
        BTFSS     STATUS, Z
        DECF      message_seconds, F

        MOVF      phase_counter_hi, F
        BTFSS     STATUS, Z
        GOTO      isr_decrement_phase
        MOVF      phase_counter_lo, F
        BTFSC     STATUS, Z
        GOTO      isr_update_cooldown
isr_decrement_phase:
        MOVLW     0x01
        SUBWF     phase_counter_lo, F
        MOVLW     0x00
        BTFSS     STATUS, C ; borrow from high byte
        MOVLW     0x01
        SUBWF     phase_counter_hi, F

isr_update_cooldown:
        MOVF      callsign_cooldown_hi, F
        BTFSS     STATUS, Z
        GOTO      isr_decrement_cooldown
        MOVF      callsign_cooldown_lo, F
        BTFSC     STATUS, Z
        GOTO      isr_second_epoch_update
isr_decrement_cooldown:
        MOVLW     0x01
        SUBWF     callsign_cooldown_lo, F
        MOVLW     0x00
        BTFSS     STATUS, C
        MOVLW     0x01
        SUBWF     callsign_cooldown_hi, F

isr_second_epoch_update:
        INCF      seconds_mod64, F
        MOVF      seconds_mod64, W
        ANDLW     0x3F
        BTFSS     STATUS, Z
        GOTO      isr_tone_update
        BSF       interrupt_flag, 1 ; 64-second epoch marker
        MOVF      timing_trim, W
        ADDWF     second_div_lo, F ; lengthen one interval per epoch
        BTFSC     STATUS, C
        INCF      second_div_hi, F

isr_tone_update:
        INCF      tone_phase, F
        MOVLW     0x88
        ADDWF     tone_phase, W ; carry when phase reaches 0x78
        BTFSC     STATUS, C
        CLRF      tone_phase ; 120-entry waveform period
        BCF       porta_shadow, 0
        BTFSC     tone_state, 7 ; silence suppresses waveform
        GOTO      isr_aux_output
        MOVF      tone_phase, W
        CALL      tone_pattern_lookup
        MOVWF     tone_pattern
        CALL      bit_mask_lookup
        ANDWF     tone_pattern, F
        BTFSC     STATUS, Z
        BSF       porta_shadow, 0

isr_aux_output:
        BCF       porta_shadow, 2
        BTFSS     tone_state, 7
        BSF       porta_shadow, 2
        BTFSS     tone_phase, 0
        GOTO      isr_signal_event
        BTFSS     tone_phase, 1
        GOTO      isr_signal_event
        MOVF      tmr0_wait_count, F
        BTFSS     STATUS, Z
        DECF      tmr0_wait_count, F ; every fourth overflow

isr_signal_event:
        BSF       interrupt_flag, 0
        MOVF      isr_status_save, W
        MOVWF     STATUS
        SWAPF     isr_w_save, F
        SWAPF     isr_w_save, W
        RETFIE
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

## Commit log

2026-07-07 Fully transcribed PDF scan
    [foxmox.kicad_sch]
2026-07-07 Fix P1, should be a plug not a jack
    [foxmox.kicad_sch]
2026-07-07 Throw in some fake footprints and start PCB
    [foxmox.kicad_pcb, foxmox.kicad_sch]
2026-07-08 Slightly better PCB
    [foxmox.kicad_pcb, foxmox.kicad_sch]
2026-08-13 Add datasheets and libraries for chosen components
    [foxmox.kicad_pcb, foxmox.kicad_sch]
2026-08-13 Smaller PCB
    [foxmox.kicad_pcb]
2026-08-13 Slightly thicker power traces
    And possibly fix transistor pins
    [foxmox.kicad_pcb, foxmox.kicad_sch]
2026-09-14 Adjust some parts, footprints, etc
    [foxmox.kicad_pcb, foxmox.kicad_sch]
2026-09-20 Change 2.5mm terminal block and add strain relief
    [foxmox.kicad_pcb, foxmox.kicad_sch]
2026-09-21 Reorganize hardware
    [foxmox.kicad_pcb, foxmox.kicad_sch]
2026-09-21 Refactor a couple of routines with mnemonics
2026-09-21 Convert EEPROM and LFSR routines to assembly
2026-09-21 Convert switch and hex display routines to assembly
2026-09-21 Convert Morse timing primitives to assembly
2026-09-21 Convert message dispatch tables to assembly
2026-09-21 Convert LFSR seed table to assembly
2026-09-21 Convert Morse composition routines to assembly
2026-09-21 Convert hexadecimal Morse table to assembly
2026-09-21 Convert message routines and correct S1 F identifier
    [foxmox-v2.6.asm]
2026-09-21 Convert tone waveform table to assembly
2026-09-21 Convert calibration service mode to assembly
2026-09-21 Convert reset and startup path to assembly
    [foxmox-v2.6.asm]
2026-09-21 Convert timer interrupt service routine to assembly
2026-09-21 Remove recovered address annotations from assembly
2026-09-21 Document clock calibration procedure
2026-09-21 Final fixup before fab
    [foxmox.kicad_pcb]
2026-09-25 Add printable FoxMox quick reference
2026-09-30 Add open hardware and github silkscreens
